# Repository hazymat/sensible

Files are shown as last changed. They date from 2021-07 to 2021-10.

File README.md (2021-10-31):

# Sensible
Sensible aims to be the **ultimate ceiling-mounted multisensor**: a Human Presence Detector with additional sensor and actuator functions. The prototype is surface mount. Ideally the multisensor would be recessed for an architectural finish, but there are additional challenges with recessing fittings such as fire safety and audio / temp sensing difficulties.

   




Description
---
The project comprises
- designs for 3D printed hardware which can be mounted to the ceiling
- designs for a PCB with various sensors / actuators attached
- a custom firmware for ESP32 with basic audio functions such as threshold, calibration, decay, retrigger
- Node-RED flows

Within:
- PIR sensor - bare component (AS312)
- Microwave sensor board (RCWL-0516)
- Temperature / humidity (currently DHT22 as it offers least self-heating and works well inside the housing) 
- Digital lux sensor (TS2561 as it provides the required resolution at very low light levels)
- LED ring for effects (SK6812 strip as I like the option of warm white as well as RGB) 
- Buzzer (for getting someone's attention in the room, or general purpose notification of emergencies etc.)

Project Progress
---
As of 04/07/2021 this is a work in progress. So far we have:
- 3D-printed sensor housing featuring a twist-lock mechanism, concealed LED pixel ring, and adaptable mounting option for baffles to limit the direction and angle of the PIR sensor
- Custom firmware supporting OTA updates, audio calibration initiated over MQTT (period of calibration set over MQTT), remote control of audio threshold, audio decay, and timing for repeat / interim audio trigger messages (configured over MQTT), audio levels reported back every x seconds that audio is above the threshold, and of course sensor data reporting back over MQTT
- Node-RED flows that hook in with the Node-RED lighting system, to allow us to set up instances of sensors, toggle individual sensing types, etc.

Design decisions
---
Wired vs. wireless. My preference has always been for wired ethernet-connected devices in the home. This project has been through a few iterations but have settled on wireless for reasons of available space in the housing. Toyed with the idea of building a board that directly supported W5100 and ATMega328 but keeping it simple to start with and will have a detachable development board. (Also means we can use space under the board as dev board will be mounted on female headers.) Power is provided via 12-24V passive PoE through network cable. The board will have an ethernet jack for ease of connecting power, but IP connection over wireless. Strange combo, but justifiable at least to get started. Ideally this board would be wired with 802.3af PoE, perhaps that's for later as this is basically designing a development board from scratch.

Photos
---
Some photos and screenshots should give a better idea of this:

- 3D-printed mount comes in two sections. This photo shows a blank bottom plate, later versions have cutouts for sensors and ventilation holes for temp / humidity


- The ring around the PIR is for attaching baffles. The circlular pattern is for airflow for the temp sensor. The small hole is for the lux sensor.


- This is version 1 of the board. We have scrapped the ESP01 and ATTiny85 and combined into one MCU, the ESP32. We are still using this ESP32 dev board which is the MH-ET LIVE MiniKit


- An early prototype showing LED ring, looks far more diffused in real life (also this was a test blank bottom plate)


- Node-RED dashboard showing PIR currently being triggered (countdown starts when trigger ends)


- Node-RED dashboard showing the lights having been triggered by microwave sensor (countdown started - timer is set elsewhere in Node-RED)


- Node-RED dashboard showing the lights not triggered (i.e. lights are off)


- PCB layout for v1. We'll be keeping the dimensions and placement of some devices, but re-designing a lot of it for version 2.


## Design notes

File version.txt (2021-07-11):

11/07/2021 - sensible-v0.91-ESP32
- replace AsyncElegantOTA (web-based OTA) with ArduionOTA. Benefit: quicker / more direct to upload OTA at least when Arduino Client is working well.
- replace Webserial with TelnetStream, prefer to use telnet for debug, keep web interface for control (not yet implemented)
- Refer wifi credentials and MQTT server variable to another file, instructions in the .ino file

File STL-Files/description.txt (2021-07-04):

All designs parametric in Fusion 360

Frontplate
Backplate
Baffle for PIR (angle and height can be altered through parameters in Fusion360)
DHT Lid (to provide separate ventilated chamber for temp sensor away from other components)

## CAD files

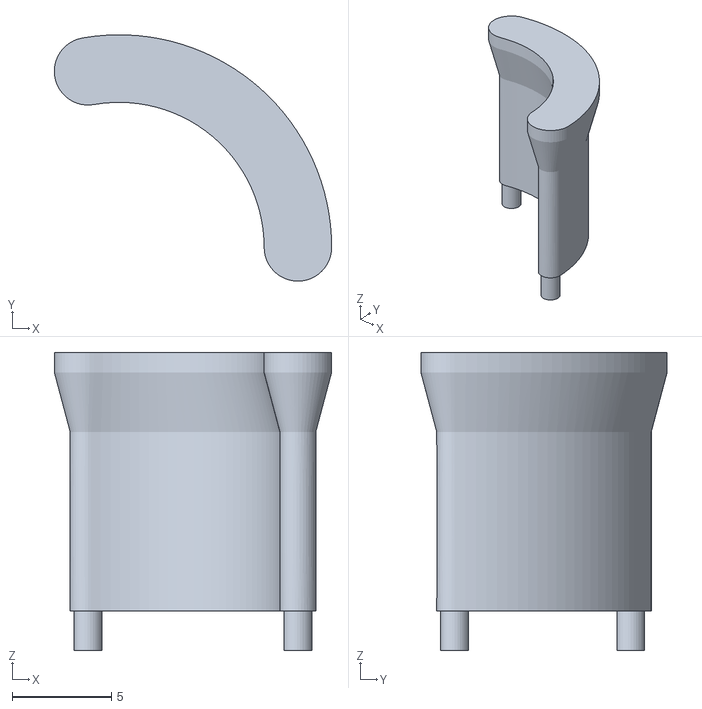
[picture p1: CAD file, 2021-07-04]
STL-Files/baffle_H_12mm.stl
14.0 x 12.4 x 15.0

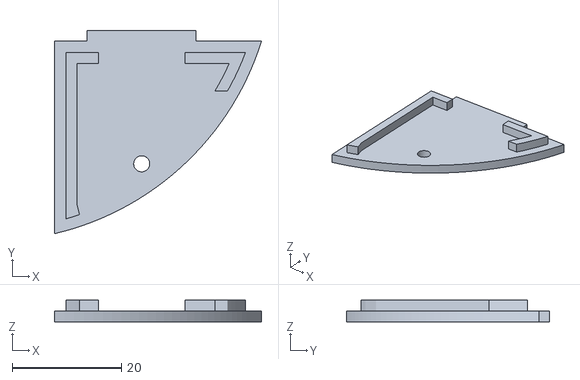
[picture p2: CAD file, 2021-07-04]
STL-Files/dht-lid-v1.stl
38.0 x 37.3 x 4.00

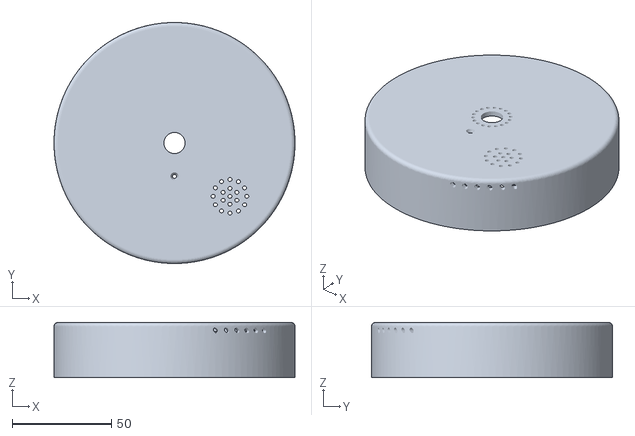
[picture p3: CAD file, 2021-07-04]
STL-Files/frontplate v9.stl
121.4 x 121.4 x 27.8

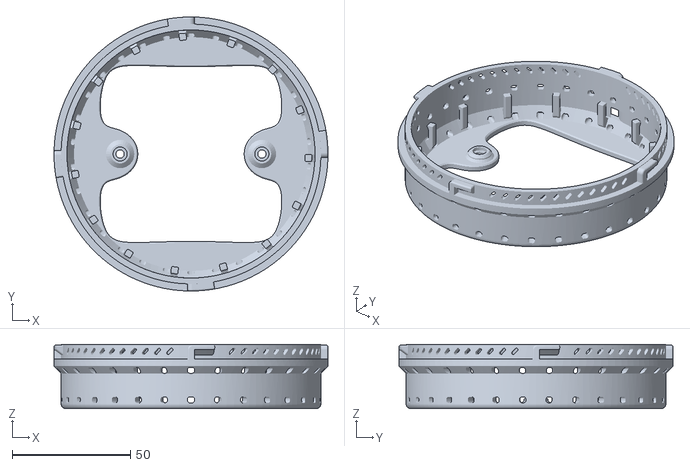
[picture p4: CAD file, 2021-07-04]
STL-Files/backplate_v8.stl
116.0 x 116.0 x 27.3

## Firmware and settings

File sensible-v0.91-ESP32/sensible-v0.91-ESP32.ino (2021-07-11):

// Include OTA.h in same directory as sketch (download: https://github.com/SensorsIot/ESP32-OTA/tree/master/0TA_Template_Sketch_TelnetStream)
// Wifi / MQTT server setup: add credentials\credentials.h in library dir, containing defines as follows: mySSID, myPASSWORD, myMQTTSERVER
// don't forget ESP32 wifi: cannot use pins 0,2,4,12-15,25-27!

/*
  Documentation
  -----------------------

  Tele messages (MQTT)
  ---
  Every 60 seconds
  fw = firmware version
  at = audio threshold setting
  ad = audio decay setting
  ar = audio repeat time (for interim audio messages)

  Calibration mode:
  ---
  Send an MQTT message to the calibration topic containing a non-zero number. The sketch will
  take max and min readings of audio level over the number of seconds specified and return this
  info over MQTT to the root topic.
*/

#include <PubSubClient.h>
#include <ArduinoJson.h>
#include "time.h"
#include "OTA.h"
#include <credentials.h>

#define CLIENTID "ESPClient-"
#define mqttroot "sensors/multisensor-002"
#define mqttcommand "sensors/multisensor-002/cmnd/#" // we subscribe to this
#define mqttthresholdset "sensors/multisensor-002/cmnd/audiothreshold"
#define mqttcalibrate "sensors/multisensor-002/cmnd/calibrate" // 0 = off, anything else = on
#define mqttdecay "sensors/multisensor-002/cmnd/decay"
#define mqttrepeat "sensors/multisensor-002/cmnd/repeat"
#define audiopin 34 // This pin is in the ADC channel 1. Pins in ADC channel 2 don't work with wifi
#define firmware "0.9"

// timers
unsigned long calibrationTimer;  // millis timer for calibration
int calibrationTime = 5; // duration of calibration in secs. Overwritten if configured over MQTT
unsigned long audioDelayTimer;
int decay = 2000; // decay time for audio
int repeatTime = 2;
unsigned long repeatTimer;
unsigned long teleTimer;

// variables
int audio = 0;
int audiothreshold = 1600; // will overwrite from settings over MQTT - 1600 works for SMD diode
bool audiostate = false;
bool prevaudiostate = false;
bool sendCalibration = false;
int calibrationmaxreading;
int calibrationminreading;
int repeatmaxreading;

// vars for timekeeping
const char* ntpServer = "pool.ntp.org";
const long  gmtOffset_sec = 0;
const int   daylightOffset_sec = 3600;

// general buffer for json / MQTT
char jsonbuff[192]; // buffer to store JSON doc

WiFiClient espClient;
PubSubClient client(espClient);

// A function that returns the local time as a pointer to a char array
static char buf [35]; // may as well define as global as needs to be static
char * printLocalTime() {
  struct tm timeinfo;
  if (!getLocalTime(&timeinfo)) {
    strcpy (buf, "[Failed to retrieve time]");
    return buf;
  }
  strftime (buf, 23, "[%F %H:%M:%S] ", &timeinfo);
  return buf;
}

// MQTT receive message
void callback(char* topic, byte* payload, unsigned int length) {
  if (strcmp(topic, mqttthresholdset) == 0) {
    payload[length] = '\0'; // null terminate it
    int value = atoi((char *)payload);     // store payload in temp var
    if (value > 0) audiothreshold = value; // check it was indeed a number
    Serial.print("Audio threshold: "); Serial.println(value);
  } else if (strcmp(topic, mqttcalibrate) == 0) {
    // calibration messages should contain a number, which corresponds to
    // the number of seconds you'd like to calibrate for
    payload[length] = '\0'; // null terminate it
    int value = atoi((char *)payload);     // store payload in temp var
    if (value > 0) {
      calibrationTime = value;
      calibrationTimer = millis();
      sendCalibration = true;
      calibrationmaxreading = 0;
      calibrationminreading = 2000;
      printLocalTime();
      Serial.print("Calibration request: "); Serial.println(calibrationTime);
    }
  } else if (strcmp(topic, mqttdecay) == 0) {
    payload[length] = '\0'; // null terminate it
    int value = atoi((char *)payload);     // store payload in temp var
    if (value > 0) {
      decay = value;
    }
  } else if (strcmp(topic, mqttrepeat) == 0) {
    payload[length] = '\0'; // null terminate it
    int value = atoi((char *)payload);     // store payload in temp var
    if (value > 0) {
      repeatTime = value;
    }
  }
  //  StaticJsonDocument<256> doc;
  //  deserializeJson(doc, payload, length);

  // React to JSON messages
  //  if (doc.containsKey("light")) {
  //    lightingtype = doc["light"];
  //    solidcolour[0] = doc["rgbw"][0];
  //    solidcolour[1] = doc["rgbw"][1];
  //    solidcolour[2] = doc["rgbw"][2];
  //    solidcolour[3] = doc["rgbw"][3];
  //  }
}

// MQTT reconnect
void reconnect() {
  // Loop until we're reconnected
  while (!client.connected()) {
    Serial.print("Attempting MQTT connection...");
    // Create a random client ID
    String clientId = CLIENTID;
    clientId += String(random(0xffff), HEX);
    // Attempt to connect
    if (client.connect(clientId.c_str())) {
      Serial.println("connected");
      // Once connected, publish an announcement...

      const int capacity = JSON_OBJECT_SIZE(3);
      StaticJsonDocument<capacity> doc;
      doc["MAC"] = "hello";
      doc["lat"] = 48.748010;
      doc["lon"] = 2.293491;
      serializeJson(doc, jsonbuff);
      client.publish(mqttroot, jsonbuff);  // buff = topic, jsonbuff = serialized json
      client.subscribe(mqttcommand);
    } else {

      Serial.print("failed, rc=");
      Serial.print(client.state());
      Serial.println(" try again in 5 seconds");
      // Wait 5 seconds before retrying
      delay(5000);
    }
  }
}


/********************************************
 *                                          *
       MAIN SETUP
 *                                          *
 *                                          *
 ********************************************/
void setup(void) {
  Serial.begin(115200);

  // Get time
  configTime(gmtOffset_sec, daylightOffset_sec, ntpServer);

  byte mac[6];                     // the MAC address of your Wifi shield
  WiFi.macAddress(mac); Serial.print("MAC: "); Serial.print(mac[5], HEX); Serial.print(":"); Serial.print(mac[4], HEX); Serial.print(":"); Serial.print(mac[3], HEX); Serial.print(":"); Serial.print(mac[2], HEX); Serial.print(":"); Serial.print(mac[1], HEX); Serial.print(":"); Serial.println(mac[0], HEX);
  client.setServer(myMQTTSERVER, 1883);
  client.setCallback(callback);
  setupOTA("Audio-Test", mySSID, myPASSWORD);
}

/********************************************
 *                                          *
       MAIN LOOP
 *                                          *
 *                                          *
 ********************************************/

void loop(void) {
  // Include as many times as we like in loop, at least every 5 secs.
  // e.g. include in for loops etc...
  ArduinoOTA.handle();

  if (millis() - calibrationTimer < calibrationTime * 1000) {
    audio = analogRead(audiopin);
    if (audio > calibrationmaxreading) calibrationmaxreading = audio;
    if (audio < calibrationminreading) calibrationminreading = audio;
  } else {
    // we are NOT in calibration mode
    // BUT, if flag set to send the results of calibration, then do that
    if (sendCalibration) {
      const int capacity = JSON_OBJECT_SIZE(3);
      StaticJsonDocument<capacity> doc;
      doc["result"] = "calibration";
      doc["max"] = calibrationmaxreading;
      doc["min"] = calibrationminreading;
      serializeJson(doc, jsonbuff);
      client.publish(mqttroot, jsonbuff);  // buff = topic, jsonbuff = serialized json
      printLocalTime();
      Serial.print("Calibration Result: Max="); Serial.print(calibrationmaxreading); Serial.print(" Min="); Serial.println(calibrationminreading);
      sendCalibration = false;
    }
    // Do audio presence sensor. High when audio above threshold. Low if decaytime has passed and audio below threshold
    audio = analogRead(audiopin);
    if (audio > audiothreshold) {
      audiostate = true;
      audioDelayTimer = millis();
    } else {
      if (millis() - audioDelayTimer > decay) {
        // if no audio, assuming decay time has elapsed
        audiostate = false;
      }
    }
    // Track state to get rising / falling edges
    if (audiostate && !prevaudiostate) {
      // rising edge
      Serial.print(printLocalTime());        Serial.println("Audio Start  .... ");
      TelnetStream.print(printLocalTime()); TelnetStream.println("Audio Start ....");
      StaticJsonDocument<192> doc;
      doc["audio"] = "start";
      serializeJson(doc, jsonbuff);
      client.publish(mqttroot, jsonbuff);  // buff = topic, jsonbuff = serialized json

      repeatTimer = millis();
      prevaudiostate = true;
      repeatmaxreading = 0; // reset the max and min audio levels for repeat messages
    } else if (!audiostate && prevaudiostate) {
      // falling edge
      Serial.print(printLocalTime());        Serial.println("Audio End  .... ");
      TelnetStream.print(printLocalTime()); TelnetStream.println("Audio End ....");
      StaticJsonDocument<192> doc;
      doc["audio"] = "end";
      serializeJson(doc, jsonbuff);
      client.publish(mqttroot, jsonbuff);  // buff = topic, jsonbuff = serialized json

      prevaudiostate = false;
    }
    if (audiostate && millis() - repeatTimer > repeatTime * 1000) {
      // audio has continued, send a repeat message

      Serial.print(printLocalTime());        Serial.print("Audio Continues .... max value: "); Serial.println(repeatmaxreading);
      TelnetStream.print(printLocalTime()); TelnetStream.print("Audio Continues ...."); TelnetStream.println(repeatmaxreading);

      StaticJsonDocument<192> doc;
      doc["audio"] = "cont";
      doc["max"] = repeatmaxreading;
      serializeJson(doc, jsonbuff);
      client.publish(mqttroot, jsonbuff);  // buff = topic, jsonbuff = serialized json

      repeatmaxreading = 0; // reset the max and min audio levels for repeat messages
      repeatTimer = millis(); // start the timer again
    } else if (audiostate && millis() - repeatTimer <= repeatTime * 1000) {
      // collect max and min for the short period of time
      if (audio > repeatmaxreading) repeatmaxreading = audio;
    }



  } // end if calibration mode off

  if (millis() - teleTimer > 60000) {
    // send tele update
    printLocalTime();
    Serial.println("Tele update");
    TelnetStream.println("Tele update");
    long rssi = WiFi.RSSI();
    String ipaddress = WiFi.localIP().toString();
    //    char ipchar[ipaddress.length()+1];
    //    ipaddress.toCharArray(ipchar,ipaddress.length()+1);
    StaticJsonDocument<192> doc;
    doc["rssi"] = rssi;
    doc["ip"] = ipaddress;
    doc["ssid"] = mySSID;
    doc["fw"] = firmware;
    doc["at"] = audiothreshold;
    doc["ad"] = decay;
    doc["ar"] = repeatTime;
    serializeJson(doc, jsonbuff);
    client.publish(mqttroot, jsonbuff);  // buff = topic, jsonbuff = serialized json
    teleTimer = millis();
  }
  // Keep MQTT connected
  if (!client.connected()) reconnect();
  client.loop();
}
